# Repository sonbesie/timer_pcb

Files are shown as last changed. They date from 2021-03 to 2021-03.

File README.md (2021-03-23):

# Timer: Printed Circuit Board (PCB)

## Description
A personal project built around a PIC microcontroller that enables or disables current flow through two independent circuits. The circuit is controlled from a computer through a USB Type-B port. This project is in the process of being modified to include two current sensors as well as an Ethernet port for data and power.

## Open
To open the project download KiCad and open the .pro file.

## Image

A render of the PCB is provided below:

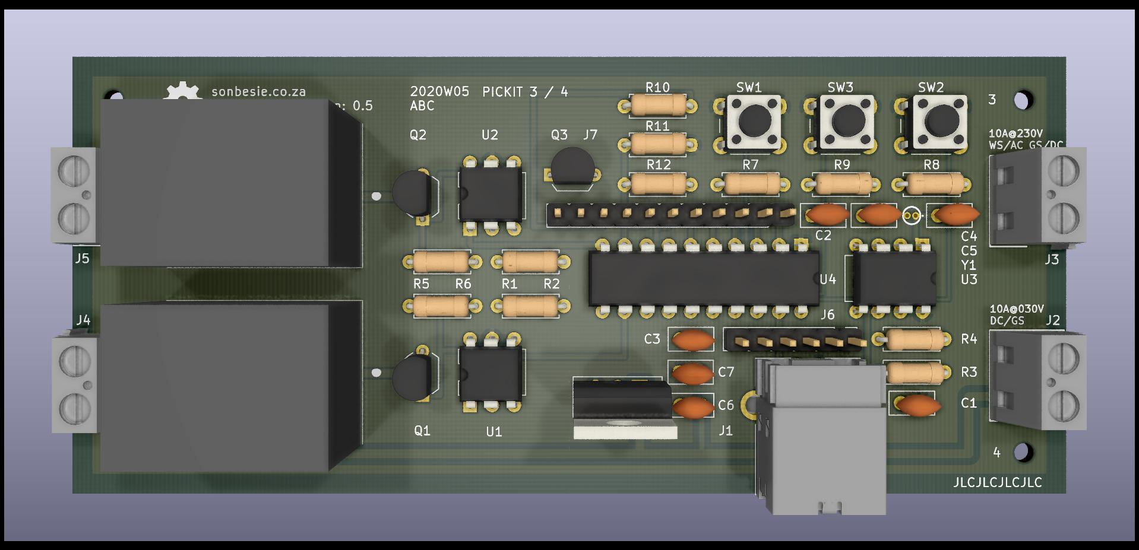
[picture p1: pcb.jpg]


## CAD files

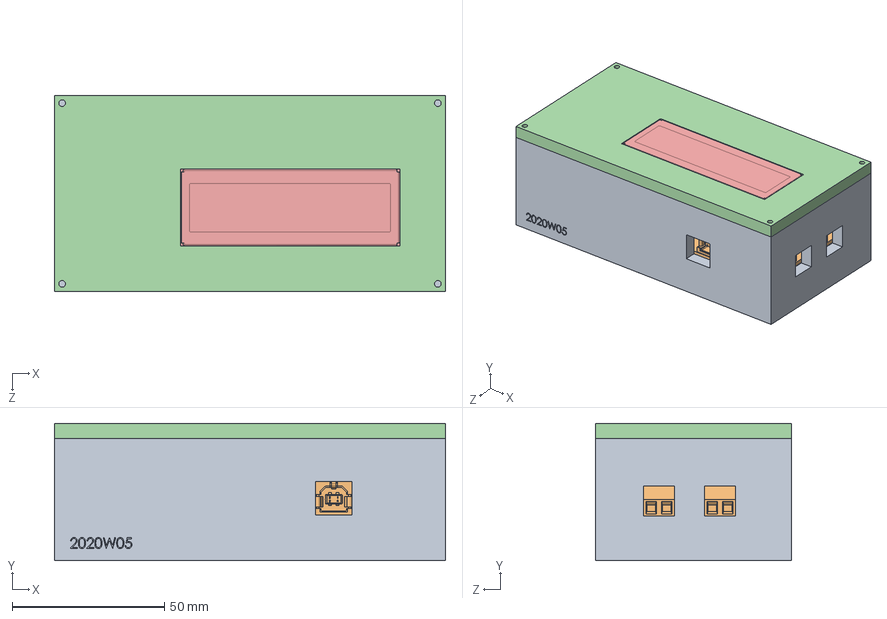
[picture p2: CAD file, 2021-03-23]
cad_model/assembly/assembly.SLDASM
128.3 x 45.0 x 64.3 mm
project_box
pcb
pcb_stand x 4
project_box_lid
screen

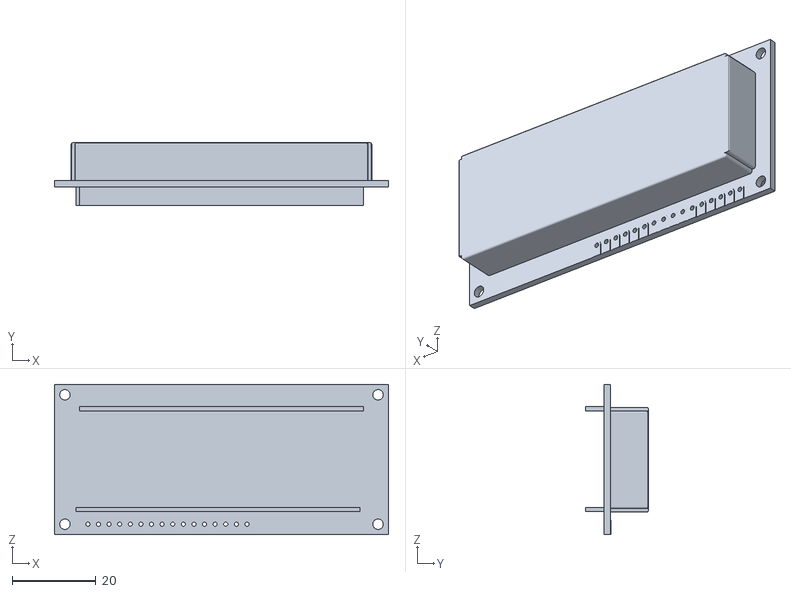
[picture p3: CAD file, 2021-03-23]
cad_model/assembly/assembly_stl/assembly - screen-1.STL
80.0 x 15.0 x 36.0

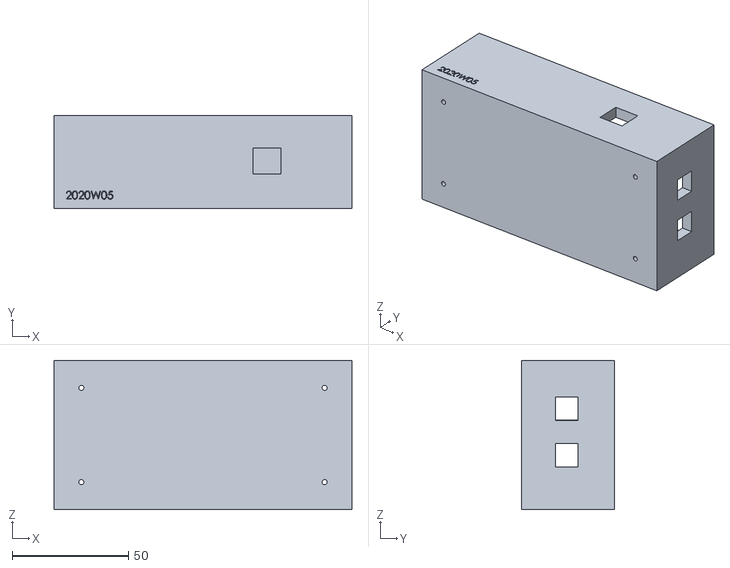
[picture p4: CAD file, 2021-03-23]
cad_model/assembly/assembly_stl/assembly - project_box-1.STL
128.3 x 40.0 x 64.3

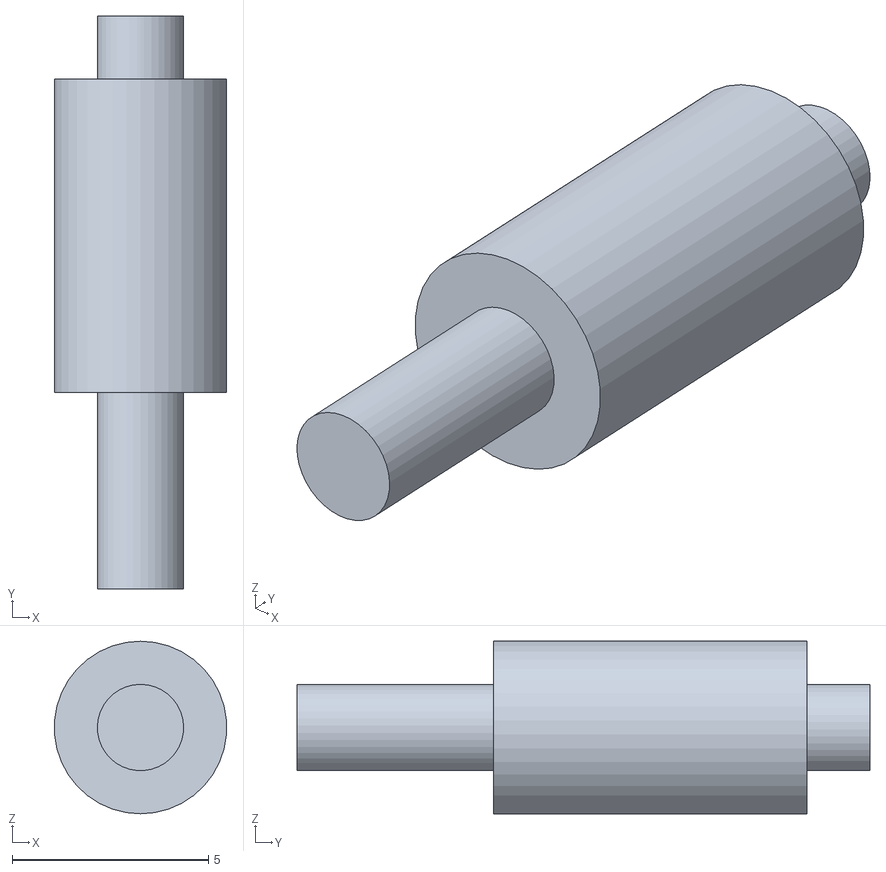
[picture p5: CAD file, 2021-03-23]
cad_model/assembly/assembly_stl/assembly - pcb_stand-3.STL
4.38 x 14.6 x 4.40

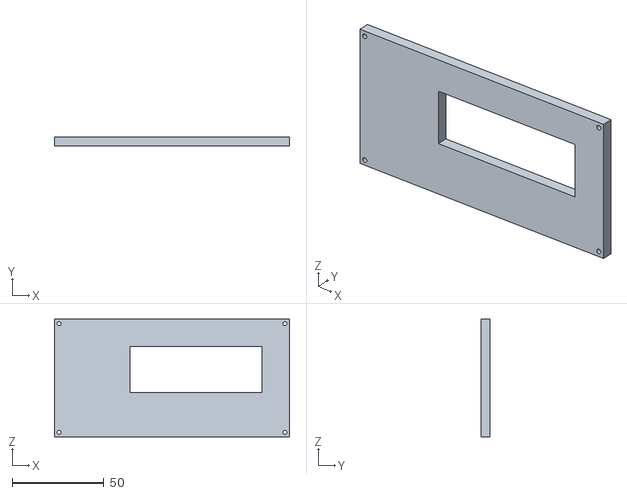
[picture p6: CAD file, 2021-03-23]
cad_model/assembly/assembly_stl/assembly - project_box_lid-1.STL
128.3 x 5.00 x 64.3

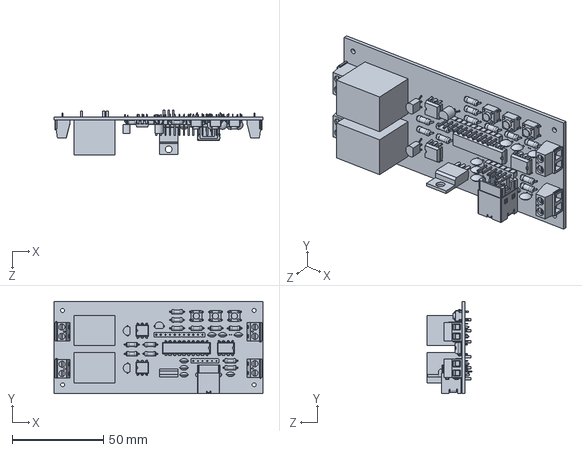
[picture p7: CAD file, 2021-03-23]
cad_model/parts/pcb.SLDPRT
114.3 x 50.4 x 24.4 mm

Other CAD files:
cad_model/assembly/assembly_stl/assembly - pcb_stand-4.STL
cad_model/assembly/assembly_stl/assembly - pcb_stand-2.STL
cad_model/assembly/assembly_stl/assembly - pcb_stand-1.STL
cad_model/parts/project_box_lid.SLDPRT
cad_model/parts/screen.SLDPRT
cad_model/parts/project_box.SLDPRT
cad_model/parts/pcb_stand.SLDPRT
cad_model/stl/pcb_stand.STL
cad_model/stl/project_box.STL
cad_model/stl/project_box_lid.STL

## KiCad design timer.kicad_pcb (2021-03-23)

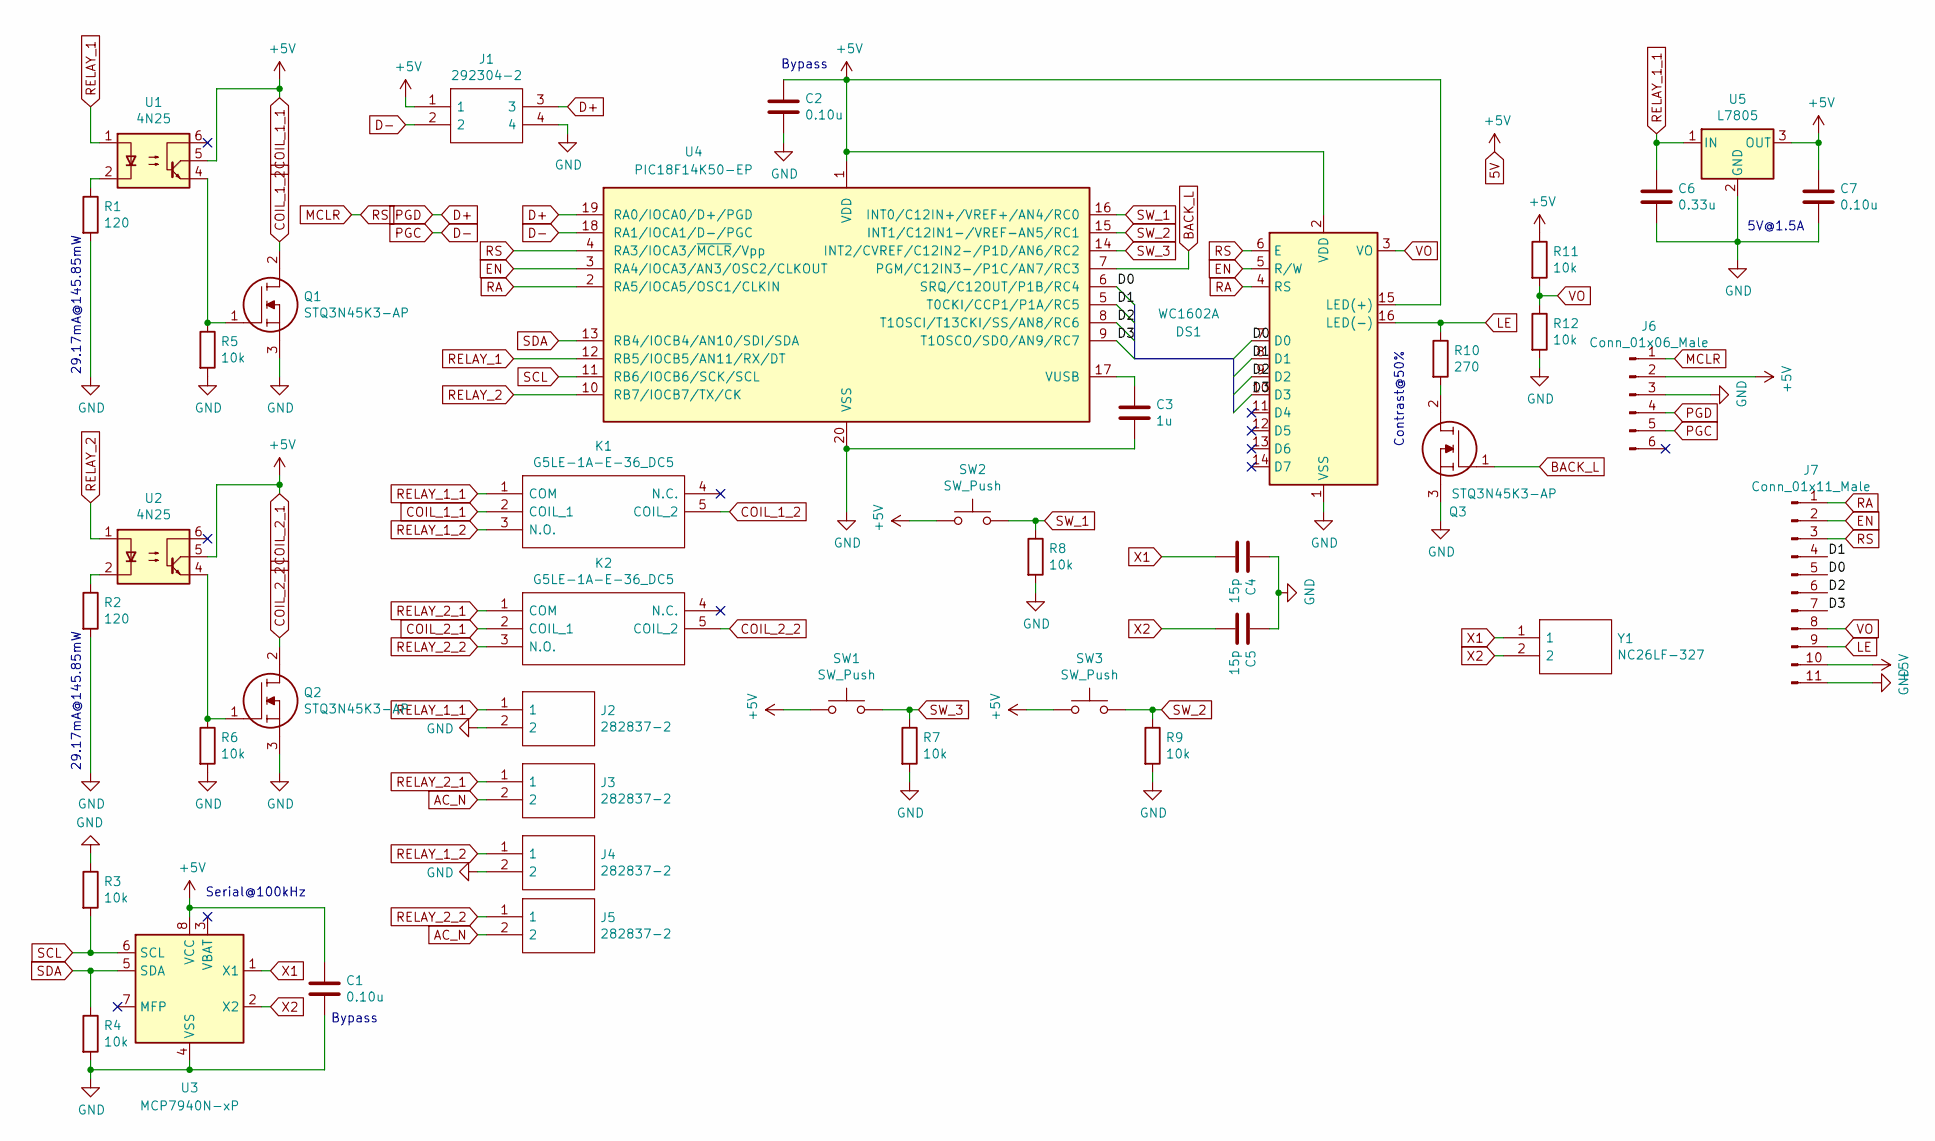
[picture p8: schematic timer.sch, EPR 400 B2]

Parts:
C1, C2, C7: 0.10u; C_Disc_D5.0mm_W2.5mm_P2.50mm
C3: 1u; C_Disc_D5.0mm_W2.5mm_P2.50mm
C4, C5: 15p; C_Disc_D5.0mm_W2.5mm_P2.50mm
C6: 0.33u; C_Disc_D5.0mm_W2.5mm_P2.50mm
DS1: WC1602A
J1: 292304-2; 292304
J2, J3, J4, J5: 282837-2; SHDR2W100P0X508_1X2_1016X820X1030P; Manufacturer_Part_Number 282837-2; Mouser Part Number 571-2828372
J6: Conn_01x06_Male; PinHeader_1x06_P2.54mm_Vertical
J7: Conn_01x11_Male; PinHeader_1x11_P2.54mm_Vertical
K1, K2: G5LE-1A-E-36_DC5; G5LE1AE36DC5; Manufacturer_Part_Number G5LE-1A-E-36 DC5; Mouser Part Number 653-G5LE-1A-E-36DC5
Q1, Q2, Q3: STQ3N45K3-AP; TO-92_Inline_Wide; Manufacturer_Part_Number STQ3N45K3-AP; Mouser Part Number 511-STQ3N45K3-AP
R1, R2: 120; R_Axial_DIN0207_L6.3mm_D2.5mm_P7.62mm_Horizontal
R3, R4, R5, R6, R7, R8, R9, R11, R12: 10k; R_Axial_DIN0207_L6.3mm_D2.5mm_P7.62mm_Horizontal
R10: 270; R_Axial_DIN0207_L6.3mm_D2.5mm_P7.62mm_Horizontal
SW1, SW2, SW3: SW_Push; SW_PUSH_6mm_H5mm
U1, U2: 4N25; DIP-6_W7.62mm
U3: MCP7940N-xP; DIP-8_W7.62mm
U4: PIC18F14K50-EP; DIP-20_W7.62mm
U5: L7805; TO-220-3_Vertical
Y1: NC26LF-327; Manufacturer_Part_Number NC26LF-327; Mouser Part Number 559-NC26-LF

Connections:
5V: C1.1, C2.1, C7.1, DS1.2 (VDD), DS1.15 (LED(+)), J1.1, J6.2, J7.10, K1.2 (COIL_1), K2.2 (COIL_1), R11.1, SW1.1, SW2.1, SW3.1, U1.5, U2.5, U3.8 (VCC), U4.1 (VDD), U5.3 (OUT)
/D0: DS1.7 (D0), J7.5, U4.6 (SRQ/C12OUT/P1B/RC4)
/D1: DS1.8 (D1), J7.4, U4.5 (T0CKI/CCP1/P1A/RC5)
/D2: DS1.9 (D2), J7.6, U4.8 (T1OSCI/T13CKI/SS/AN8/RC6)
/D3: DS1.10 (D3), J7.7, U4.9 (T1OSCO/SDO/AN9/RC7)
AC_N: J3.2, J5.2
BACK_L: Q3.1, U4.7 (PGM/C12IN3-/P1C/AN7/RC3)
COIL_1_2: K1.5 (COIL_2), Q1.2
COIL_2_2: K2.5 (COIL_2), Q2.2
D+: J1.3, J6.4, U4.19 (RA0/IOCA0/D+/PGD)
D-: J1.2, J6.5, U4.18 (RA1/IOCA1/D-/PGC)
EN: DS1.5 (R/W), J7.2, U4.3 (RA4/IOCA3/AN3/OSC2/CLKOUT)
GND: C1.2, C2.2, C3.2, C4.1, C5.1, C6.2, C7.2, DS1.1 (VSS), J1.4, J2.2, J4.2, J6.3, J7.11, Q1.3, Q2.3, Q3.3, R1.2, R2.2, R3.1, R4.2, R5.2, R6.2, R7.2, R8.2, R9.2, R12.2, U3.4 (VSS), U4.20 (VSS), U5.2 (GND)
LE: DS1.16 (LED(-)), J7.9, R10.1
MCLR: DS1.6 (E), J6.1, J7.3, U4.4 (RA3/IOCA3/~MCLR~/Vpp)
unnamed: C3.1, U4.17 (VUSB)
unnamed: Q1.1, R5.1, U1.4
unnamed: Q2.1, R6.1, U2.4
unnamed: Q3.2, R10.2
unnamed: R1.1, U1.2
unnamed: R2.1, U2.2
RA: DS1.4 (RS), J7.1, U4.2 (RA5/IOCA5/OSC1/CLKIN)
RELAY_1: U1.1, U4.12 (RB5/IOCB5/AN11/RX/DT)
RELAY_1_1: C6.1, J2.1, K1.1 (COM), U5.1 (IN)
RELAY_1_2: J4.1, K1.3 (N.O.)
RELAY_2: U2.1, U4.10 (RB7/IOCB7/TX/CK)
RELAY_2_1: J3.1, K2.1 (COM)
RELAY_2_2: J5.1, K2.3 (N.O.)
SCL: R3.2, U3.6 (SCL), U4.11 (RB6/IOCB6/SCK/SCL)
SDA: R4.1, U3.5 (SDA), U4.13 (RB4/IOCB4/AN10/SDI/SDA)
SW_1: R8.1, SW2.2, U4.16 (INT0/C12IN+/VREF+/AN4/RC0)
SW_2: R9.1, SW3.2, U4.15 (INT1/C12IN1-/VREF-AN5/RC1)
SW_3: R7.1, SW1.2, U4.14 (INT2/CVREF/C12IN2-/P1D/AN6/RC2)
VO: DS1.3 (VO), J7.8, R11.2, R12.1
X1: C4.2, U3.1 (X1), Y1.1
X2: C5.2, U3.2 (X2), Y1.2

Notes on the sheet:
29.17mA@145.85mW
Serial@100kHz
Contrast@50%
5V@1.5A
Bypass

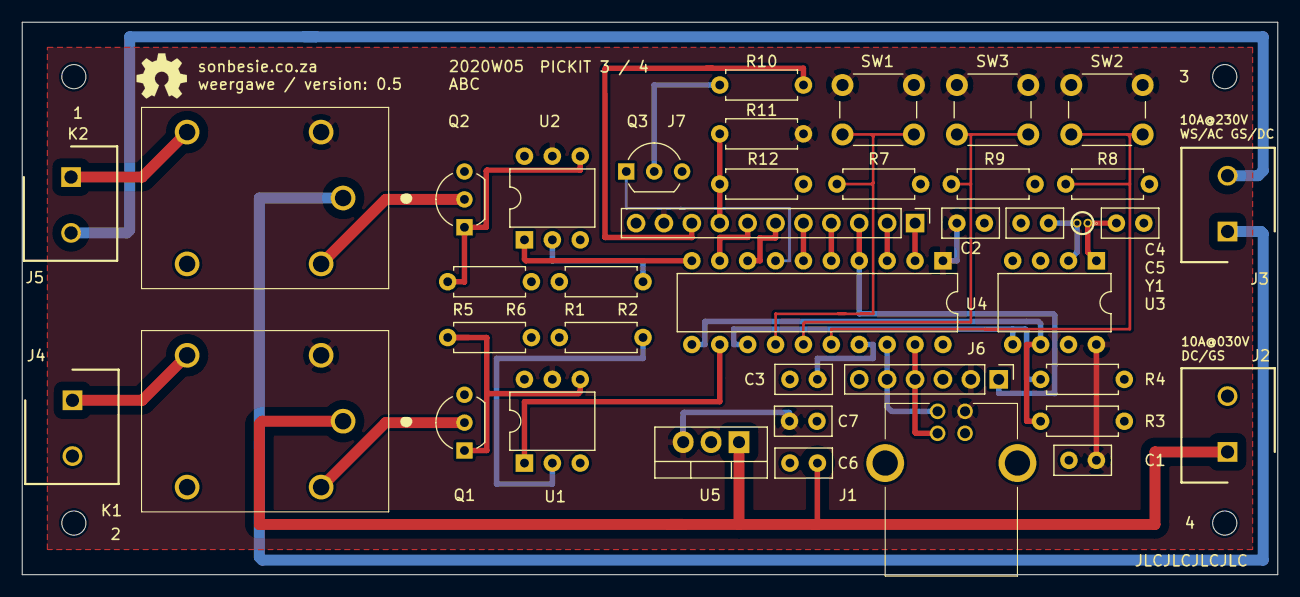
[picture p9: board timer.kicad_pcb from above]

Board: 2 copper layers, 114.3 x 50.3 mm, 45 parts (0 on the bottom side), 36 nets.

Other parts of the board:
1, 2, 3, 4: MountingHole_2.2mm_M2
5: OSHW-Logo2_7.3x6mm_SilkScreen

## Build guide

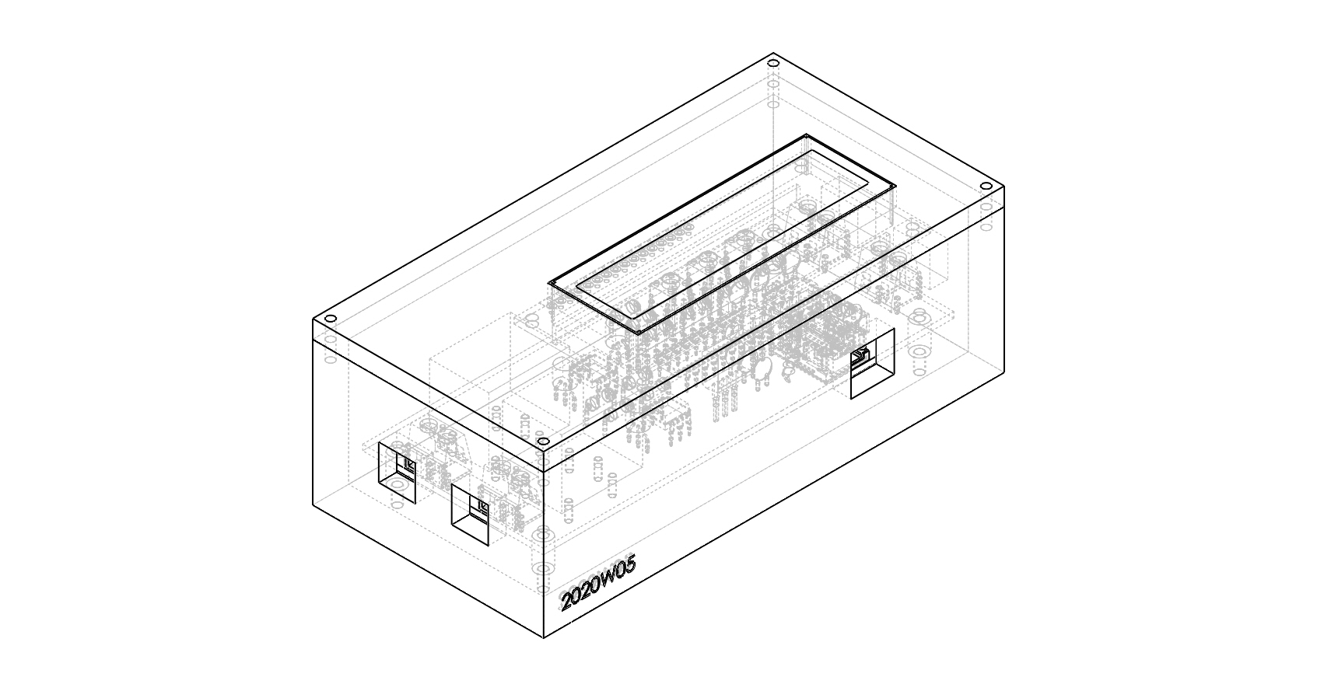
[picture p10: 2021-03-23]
cad_model/assembly/assembly_s.JPG

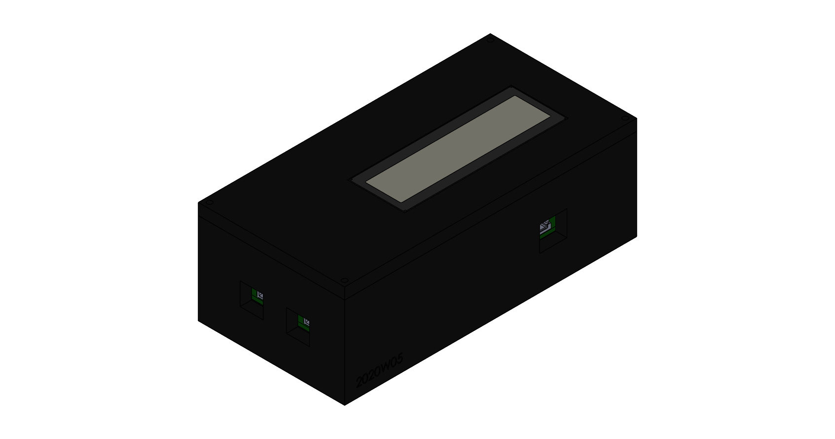
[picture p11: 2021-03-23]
cad_model/assembly/assembly.JPG

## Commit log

2021-03-23 first github commit
    [assembly - pcb_stand-1.STL, assembly - pcb_stand-2.STL, assembly - pcb_stand-3.STL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]
2021-03-23 Update README.md
    updated the pcb image
